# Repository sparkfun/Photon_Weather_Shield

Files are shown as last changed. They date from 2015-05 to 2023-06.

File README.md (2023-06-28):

⛔️ Discontinued
====================
*This product has been retired from our catalog.*

SparkFun_Photon_Weather_Shield
===========================

Photon Weather Shield

[*Photon Weather Shield (DEV-13630 )*](https://www.sparkfun.com/products/13630)

The SparkFun Photon Weather Shield is an easy to use add-on board for the Photon form Particle.io, which  grants you access to barometric pressure, relative humidity, and temperature. There are also connections on this shield to optional sensors such as wind speed, direction, rain gauge and soil readings!

Repository Contents
-------------------

* **/Firmware** - Necessary libraies and example sketches to use the weather shield. 
* **/Hardware** - All Eagle design files (.brd, .sch)
* **/Production** - Test bed files and production panel files

Documentation
--------------
* **[Hookup Guide](https://learn.sparkfun.com/tutorials/photon-weather-shield-hookup-guide)** - Complete hookup guide for the Photon Wetaher Shield.
* **[SparkFun Fritzing repo](https://github.com/sparkfun/Fritzing_Parts)** - Fritzing diagrams for SparkFun products.
* **[SparkFun 3D Model repo](https://github.com/sparkfun/3D_Models)** - 3D models of SparkFun products. 

Product Versions
----------------
* [DEV-13630](https://www.sparkfun.com/products/13630)- Hardware version 1.0

Version History
---------------

License Information
-------------------

This product is _**open source**_! 

Please review the LICENSE.md file for license information. 

If you have any questions or concerns on licensing, please contact techsupport@sparkfun.com.

Distributed as-is; no warranty is given.

- Your friends at SparkFun.

MenloParkInnovation LLC Fork of SparkFun_Photon_Weather_Shield
===========================

The MenloParkInnovation LLC Fork of the SparkFun WeatherShield contains fixes for
the Phant HTTP transfer loop, and a re-written version of the main project
that adds Particle Cloud management, and connections to Smartpux/Openpux
at https://github.com/menloparkinnovation/openpux

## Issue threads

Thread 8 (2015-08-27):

New Photon Weather Shield Library

JoelEB, 2015-08-27:
@danfein Hi, just so you're aware, I combined the HTU21D, Si7021 and MPL3115A2 libraries into one library, found here: https://github.com/sparkfun/SparkFun_Photon_Weather_Shield_Particle_Library. This was mostly to eliminate the need to import two libraries while using the Particle Build IDE. It was also created to support both the HTU21D and Si7021 temp/humidity sensors. We had to switch to the SI7021 on some of our batches due to shortages of the HTU and to meet our deadline with Microsoft. We will be switching the Si chip in a future revision of the shield, so this allows the end user to use both version so the shield seamlessly. If you want to incorporate that new library into your example, fell free. Thanks again.

Closed 2016-03-03.

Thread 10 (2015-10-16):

Variable 'dailyrainin' never resets

georgep56, 2015-10-16:
I'm new to GitHub so I'm sorry if I'm not following protocol ;-)

In the file 'SparkFun_Photon_Weather_Basic_Soil_Meters.ino' I've noticed that the value 'dailyrainin' (rain inches so far today in local time) never gets reset. I've made this small addition to my code towards the bottom of 'loop()':

```
    currentTime = Time.now();

    if ((Time.hour(currentTime) == 0) && (Time.minute(currentTime) == 0) && (Time.second(currentTime) == 0)){
        DailyRainIn = 0;
    }
```

jim-c-sims, 2016-02-13:
I noticed the same thing. I'm guessing that I need to add an I2C real time clock. Is that what you did?

georgep56, 2016-02-13:
Yes, my hardware comprised an arduino and an i2c rtc so had access to the time of day.

wmjenk, 2016-02-13:
Note that the method George used gets current UTC time and would need to be corrected for your time zone if you want to reset at midnight local time. Note also that the UTC time does not adjust for daylight savings time. George’s code works fine with the photon and the weather shield just adjust for your time zone.

Bill

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

santaimpersonator, 2023-06-28:
This product has been retired for some time now and this issue hasn't been addressed for a while. I am closing this issue before archiving the repo.

Closed 2023-06-28.

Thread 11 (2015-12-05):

Wind Direction changes needed if you plan to upload to Weather Underground

wmjenk, 2015-12-05:
Note that "winddir" in the sample code is parsed by the value of the ADC ranges into eight integers 0-7 representing N,NE,E,SE,S,SW,W,NW. The sample code then uses these 0-7 integers to select the correct direction text to output to the serial line. However Weather Underground is expecting "winddir" to be an integer between 0-360 representing a direction in degrees. A simple solution is to replace the integers 0-7 in the get_wind_direction with the direction in degrees, 0, 45, 90,135,180,225,270,315. The same directional integer values can be substituted for the 0-7 values in the serial print routine. Note also that the get_wind_direction routine returns a "-1" if it fails to return one of the defined adc range values. This is a problem for Weather Underground as a -1 is considered an inappropriate value for wind direction and the site will be flagged for reporting inaccurate data. You should avoid uploading any wind directional data values outside the 0-360 range to Weather Underground.

santaimpersonator, 2023-06-28:
This product has been retired for some time now and this issue hasn't been addressed for a while. I am closing this issue before archiving the repo.

Closed 2023-06-28.

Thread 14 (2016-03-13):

Windspeedmph step function

hartmms, 2016-03-13:
I modified the X to post several variables up to Weather Underground. I'm noticing the windspeedmph variable has very few values: 0, 7.2, 14.5, etc.  Is anyone else noticing the same thing?

cwrisley, 2016-03-14:
yes, I noticed the same thing (sort of)
I added
Spark.publish("Wind Speed", String(windspeedmph) + "mph");
delay(2000);
So I could monitor the figures on that I was uploading, and I see alot of this:
{"data":"3.926316mph","ttl":"60","published_at":"2016-03-14T00:29:14.482Z","coreid":"XXXXXXXXX","name":"Wind Speed"}
{"data":"3.905759mph","ttl":"60","published_at":"2016-03-14T00:30:26.544Z","coreid":"XXXXXXXXX","name":"Wind Speed"}
{"data":"7.852632mph","ttl":"60","published_at":"2016-03-14T00:28:01.617Z","coreid":"XXXXXXXXX","name":"Wind Speed"}

Summary: they are "different" numbers, but they seem to close to be true...

hartmms, 2016-03-14:
What frequency are you  calling the "getWeather()"  function. That's the one that actually sets that variable.

Looking at the code closer, the "loop" runs every second and always calls get_wind_speed before "getWeather()":
```
currentSpeed = get_wind_speed()
.
.
.
if (count == X) {
  getWeather()
    windspeedmph = get_wind_speed()
```

So the windspeedmph variable really isn't much different than "currentSpeed". Also note the 2nd call to "get_wind_speed" happens as fast as the code can execute the stuff in between (and other system tasks). I'll bet this elapsed time is so small there are very few windIRQs, causing the step function we see. I'll change my code to post "currentSpeed", which would allow the windIRQ to have a full second of counts to calculate from. Maybe that would result in something better.

cwrisley, 2016-03-14:
Not going to lie, I'm very new to this (aka this is my first ever project of any sort), I'll try to answer... I started with the code posted here on github, but really did alot of commenting it out to get it to post "some" data to wunderground (still working on other fields (windgust etc...http://www.wunderground.com/personal-weather-station/dashboard?ID=KNYESSEX3#history), so I'll try to answer.

I think this answers your question:

 getWeather();
    //Rather than use a delay, keeping track of a counter allows the photon to
    // still take readings and do work in between printing out data.
    count++;
    //alter this number to change the amount of time between each reading
    if(count == 5)
    {
       printInfo();
       count = 0;

    //Send data to Weather Underground
        sendToWU();
    }
  }

I do recall having to mess around and getting errors when trying to save around current speed and wind speed, I might have switched them around at some point....

int WDIR = A0;
int RAIN = D2;
int WSPEED = D3;
int currentTime = 0;

//Global Variables
//-=-=-=-=-=-=-=-=-=-=-=-=-=-=-=-=-=-=-=-=-=-=-=-=-=-=-=-=
long lastSecond; //The millis counter to see when a second rolls by
byte seconds; //When it hits 60, increase the current minute
byte seconds_2m; //Keeps track of the "wind speed/dir avg" over last 2 minutes array of data
byte minutes; //Keeps track of where we are in various arrays of data
byte minutes_10m; //Keeps track of where we are in wind gust/dir over last 10 minutes array of data

int winddir = 0; // [0-360 instantaneous wind direction]
float windspeedmph = 0; // [mph instantaneous wind speed]
float windgustmph = 0; // [mph current wind gust, using software specific time period]
int windgustdir = 0; // [0-360 using software specific time period]
float windspdmph_avg2m = 0; // [mph 2 minute average wind speed mph]
int winddir_avg2m = 0; // [0-360 2 minute average wind direction]
float windgustmph_10m = 0; // [mph past 10 minutes wind gust mph ]
int windgustdir_10m = 0; // [0-360 past 10 minutes wind gust direction]
float rainin = 0; // [rain inches over the past hour)] -- the accumulated rainfall in the past 60 min
long lastWindCheck = 0;
volatile float dailyrainin = 0; // [rain inches so far today in local time]
volatile long lastWindIRQ = 0;
volatile byte windClicks = 0;
volatile unsigned long raintime, rainlast, raininterval, rain;
float humidity = 0;
float tempf = 0;
float tempc = 0;
//double InTempC = 0;//original temperature in C from DS18B20
//float soiltempf = 0;//converted temperature in F from DS18B20
float dewptc = 0;
float dewptF = 0;
float dewptf = 0;
float dewptC = 0;
float tempC = 0;
float pascals = 0;
float altf = 0;
float baroTemp = 0;
//int soilMoisture = 0;
float humTempF = 0;  //humidity sensor temp reading, fahrenheit
float humTempC = 0;  //humidity sensor temp reading, celsius
float baroTempF = 0; //barometer sensor temp reading, fahrenheit
float baroTempC = 0; //barometer sensor temp reading, celsius
float inches = 0;

int count = 0;

void wspeedIRQ()
// Activated by the magnet in the anemometer (2 ticks per rotation), attached to input D3
{
  if (millis() - lastWindIRQ > 10) // Ignore switch-bounce glitches less than 10ms (142MPH max reading) after the reed switch closes
  {
    lastWindIRQ = millis(); //Grab the current time
    windClicks++; //There is 1.492MPH for each click per second.
  }
}

________________

hartmms, 2016-03-14:
Thanks for the input, but I'm not sure that will fix the issue. Based on my testing, I'm pretty sure it's the 2nd call to get_wind_speed() so close to the original call that leaves nearly zero time for "windIRQ" to trigger and generate any meaningful samples.

I re-worked the loop() body to only get the wind speed every 5 seconds. This means I removed the "get_wind_speed" from getWeather() also. Some debug publish events later, and I can see much more realistic wind measurements. No more step function!

Unfortunately, I've added so much of my own custom code that submitting a pull request is no longer appropriate.

However, here is a sample of the new wind measurement part of my loop():

```
    long now = Time.now();
    hour = Time.hour(now);
    minute = Time.minute(now);
    second = Time.second(now);
    // If a new day, reset vars that keep the daily totals
    if (hour == 0 && minute == 0 && second == 0) {
      dailyrainin = 0;
      windgustmph = 0;
    }
    //Calc the wind speed every 5 seconds
    if ((second+1) % 5 == 0) {
      currentSpeed = get_wind_speed();
      int currentDirection = get_wind_direction();
      windspdavg[seconds_2m] = (int)currentSpeed;
      winddiravg[seconds_2m] = currentDirection;
      //Check to see if this is a gust for the minute
      if (currentSpeed > windgust_10m[minutes_10m]) {
        windgust_10m[minutes_10m] = currentSpeed;
        windgustdirection_10m[minutes_10m] = currentDirection;
      }
      //Check to see if this is a gust for the day
      if (currentSpeed > windgustmph) {
        windgustmph = currentSpeed;
        windgustdir = currentDirection;
      }
    }
```

I'm now using the currentSpeed variable to post the WU value of "windspeedmph". Be sure to remove the winddir, windspeedmph, windgustmph, windgustdir from the getWeather() function.

gringofr, 2020-07-11:
hello hartmms,
It has been several weeks since I have broken my head with the code for my weather station, will you be kind enough to share your code which looks functional.

thank you in advance

santaimpersonator, 2023-06-28:
This product has been retired for some time now and this issue hasn't been addressed for a while. I am closing this issue before archiving the repo.

Closed 2023-06-28.

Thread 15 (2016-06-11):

rain sensor triggers incorrectly

hartmms, 2016-06-11:
Anyone else seeing the rain IRQ trigger incorrectly? I see the code has some basic debounce code to it, so I doubt that's the issue.  Is the sensor that sensitive to vibration/high wind gusts?

santaimpersonator, 2023-06-28:
This product has been retired for some time now and this issue hasn't been addressed for a while. I am closing this issue before archiving the repo.

Closed 2023-06-28.

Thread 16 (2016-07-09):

Does not work with negative temperatures on 32-bit processors

jkardach, 2016-07-09:
Hi,
On an ARM processor the temperature is not converted from the two byte registers into a float correctly and the sign is not extended resulting in a large positive number when the temperature goes below zero.
The issue occurs in the rawToCelisius method, where it a sixteen bit integer into a four byte float.  I'm guessing the casting of the 16-bit integer raw to a float must first cast to a 4 byte integer without sign-extending the upper two bytes, which then results in a larger positive integer (versus a small negative integer) before it is converted to a float.

// convert from raw to Celsius
float DallasTemperature::rawToCelsius(int16_t raw)
{
    if (raw <= DEVICE_DISCONNECTED_RAW)
        return DEVICE_DISCONNECTED_C;
    // C = RAW/128
    return (float)raw \* 0.0078125;
}

I was able to get negative results by doing the following:

```
    int temp4 = RAW;      // on ARM this is a 4byte integer, upper two bytes zero
if (RAW&0x8000) {    // check high bit of RAW to see if negative
    temp4 = temp4 | 0xFFFF0000;    // sign extend to upper 2 bytes for negative
} else {
    temp4 = temp4 & 0x0000FFFF;  // sign extend to upper 2 bytes for positive
}
    return (float) temp4* 0.0078125;        // convert to floating
```

I'm not a a great programmer, but I figure someone who is can update the library so that it will work properly on 32-bit, 16-bit and 8-bit processors.

thanks,
Jim Kardach

santaimpersonator, 2023-06-28:
This product has been retired for some time now and this issue hasn't been addressed for a while. I am closing this issue before archiving the repo.

Closed 2023-06-28.

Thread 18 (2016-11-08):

v11 checklist issues

ericorosel, 2016-11-08:
(1) The "SDA" trace is exposed by the tSTOP of R5. The trace could be moved down to eliminate excessive tSTOP related trace exposure.

(2) The "3.3V" trace is exposed by pin 4 of the MPL. The trace could be moved down to eliminate excessive tSTOP related trace exposure.

(3) It looks like the Si7021 package is missing tSTOP for the center pad, but does have a tCREAM polygon. As it stands, it looks like we will be pasting onto mask where the center pad will should be. This is also present in the Weather Shield which uses the same package.

JoelEB, 2016-11-08:
Fixed tSTOP of 1) and 2).

Added tSTOP to Si7021 footprint in parts library, Updated part on both this board as well as the Arduino Weather Shield. Rev.

Closed 2016-11-08.

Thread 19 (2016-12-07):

Double check v11

edspark, 2016-12-07:
1) Are any jumpers labeled clearly by their function and possible settings? [YES]
comment: SJ3 Jumper has a spelling error "dissconnect" instead of "disconnect".

2) Have you verified that the BOM in Sparkle is accurate (also checking for PROD_ID, NAME, VALUE, PREFIX)? [YES]
comment: Missing CONN-09696 on the BOM and CONN-13002 is on the Sparkle Page but not on the BOM

3) Does it pass SparkFun DRC? [NO]
comment: No but we cruised through all 250+ errors and it's cool Joel.

4) Do all footprints have 0.008 inch silk footprint? [NO]
comment: Nope but its cool.

5) Is the polarity label outside of the package for visibility after part population? [NO]
comment: NO but it's cool.

6) The values for Diodes D8, D10, and D6 overlap nearby nets!

JoelEB, 2016-12-09:
Pete - What do you mean by "CONN-13002 is on the Sparkle Page but not on the BOM" I see it in the BOM in Sparkle. They've been building them correctly thus far, so I'm assuming it's correct.

Fixed issue 1 and 6. Discussed issues 3, 4 and 5 with Pete in person.

Closing.

Closed 2016-12-09.

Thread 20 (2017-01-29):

sensors is wrong, does not compile for 6 ino files

hanscees, 2017-01-29:
hi

sensors.begin();
does not compile.
all sensorS should be sensor. S is wrong. Error introduced with soil temperature code

this error is in all ino files made 11 months ago. Took me a while to find it.

santaimpersonator, 2023-06-28:
This product has been retired for some time now and this issue hasn't been addressed for a while. I am closing this issue before archiving the repo.

Closed 2023-06-28.

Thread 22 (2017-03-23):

Arduino & photon weather shield

WillemSpectrum, 2017-03-23:
Are you somehow able to hook up the sparkfun photon weather shield to an arduino genuino uno?

Thanks in advance

JoelEB, 2017-03-23:
Hi, If you're looking for something that will fit on an Uno, check out our[ Arduino Weather Shield](https://www.sparkfun.com/products/13956). It is very similar to the Photon Weather Shield.

WillemSpectrum, 2017-03-24:
@JoelEB alright thank you, i think me and my classmate have made the wrong purchase then.

Closed 2017-03-23.

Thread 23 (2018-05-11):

No need to wait after Wire.requestFrom().

Koepel, 2018-05-11:
See https://github.com/sparkfun/SparkFun_Photon_Weather_Shield_Particle_Library/issues/6

santaimpersonator, 2023-06-28:
This product has been retired for some time now and this issue hasn't been addressed for a while. I am closing this issue before archiving the repo.

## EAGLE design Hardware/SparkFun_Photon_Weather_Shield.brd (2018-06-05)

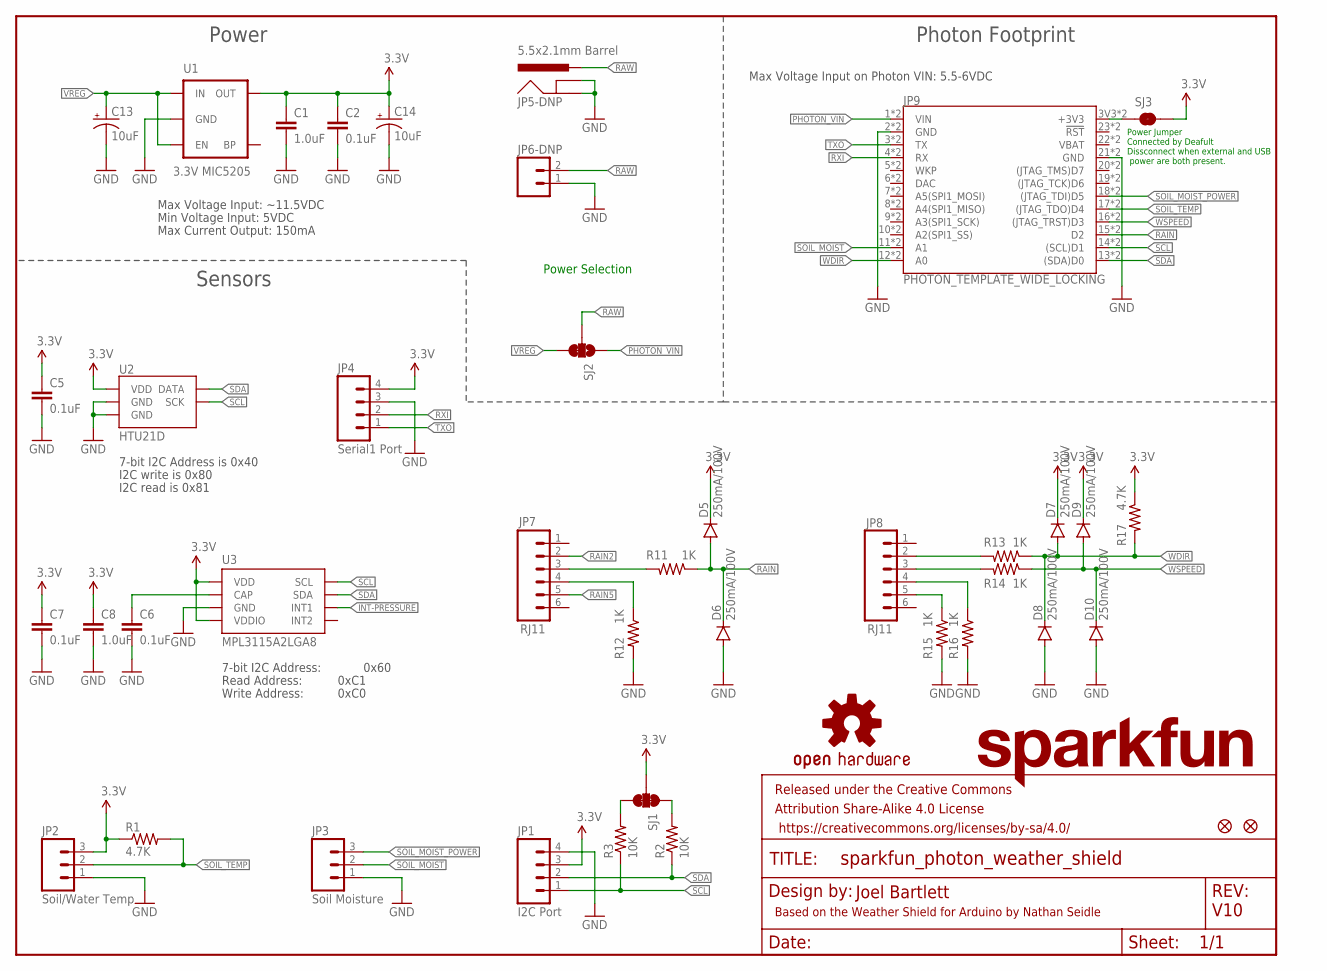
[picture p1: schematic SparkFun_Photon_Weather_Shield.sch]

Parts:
C1, C8: 1.0uF; 0603-CAP
C2, C5, C6, C7: 0.1uF; 0603-CAP
C13, C14: 10uF; EIA3216
D5, D6, D7, D8, D9, D10: 250mA/100V; SOD-323
FID1, FID2: FIDUCIAL1X2; FIDUCIAL-1X2
FRAME1: FRAME-LETTER; CREATIVE_COMMONS
JP1: I2C Port; 1X04
JP2: Soil/Water Temp; 1X03
JP3: Soil Moisture; 1X03
JP4: Serial1 Port; 1X04
JP5-DNP: 5.5x2.1mm Barrel; POWER_JACK_SMD
JP6-DNP: M023.5MM; SCREWTERMINAL-3.5MM-2
JP7, JP8: RJ11; RJ11-6
JP9: PHOTON_TEMPLATE_WIDE_LOCKING; SPARK_PHOTON_TEMPLATE_WIDE_LOCKING
LOGO1: OSHW-LOGOM; OSHW-LOGO-M
LOGO2: SFE_LOGO_NAME.1_INCH; SFE_LOGO_NAME_.1
R1, R17: 4.7K; 0603-RES
R2, R3: 10K; 0603-RES
R11, R12, R13, R14, R15, R16: 1K; 0603-RES
SJ1: JUMPER-PAD-3-NC_BY_TRACE; PAD-JUMPER-3-3OF3_NC_BY_TRACE_YES_SILK_FULL_BOX
SJ2: JUMPER-PAD-3-2OF3_NC_BY_TRACE_SMALL; PAD-JUMPER-3-2OF3_NC_BY_TRACE_YES_SILK_FULL_BOX
SJ3: JUMPER-PAD-2-NC_BY_TRACE; PAD-JUMPER-2-NC_BY_TRACE_YES_SILK
U1: 3.3V MIC5205; SOT23-5
U2: HTU21D
U3: MPL3115A2LGA8; LGA8

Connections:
3.3V: C1.1, C2.1, C5.1, C7.1, C8.1, C14.A (+), D5.C, D7.C, D9.C, JP1.3, JP2.3, JP4.4, R1.1, R17.1, SJ1.2, SJ3.2, U1.5 (OUT), U2.VDD, U3.1 (VDD), U3.4 (VDDIO)
GND: C1.2, C2.2, C5.2, C6.2, C7.2, C8.2, C13.C (-), C14.C (-), D6.A, D8.A, D10.A, JP1.4, JP2.1, JP3.1, JP4.3, JP5-DNP.GND (GNDBREAK), JP5-DNP.P$4 (GND), JP6-DNP.1, JP9.2 (GND), JP9.21 (GND), JP9.GND@0 (GND), JP9.GND@2 (GND), R12.2, R15.2, R16.2, U1.2 (GND), U2.7 (GND), U2.GND, U3.3 (GND)
INT-PRESSURE: U3.6 (INT1)
unnamed: JP8.3, R14.2
unnamed: JP8.2, R13.2
unnamed: R3.2, SJ1.3
unnamed: JP7.3, R11.2
unnamed: C6.1, U3.2 (CAP)
unnamed: R2.2, SJ1.1
unnamed: JP9.3V3 (+3V3), JP9.24 (+3V3), SJ3.1
unnamed: JP7.4, R12.1
unnamed: JP8.5, R15.1
unnamed: JP8.4, R16.1
PHOTON_VIN: JP9.1 (VIN), JP9.VIN, SJ2.1
RAIN: D5.A, D6.C, JP9.15 (D2), JP9.D2, R11.1
RAIN2: JP7.2
RAIN5: JP7.5
RAW: JP5-DNP.VIN0 (PWR), JP6-DNP.2, SJ2.2
RXI: JP4.2, JP9.4 (RX), JP9.RX
SCL: JP1.1, JP9.14 ((SCL)D1), JP9.D1 ((SCL)D1), R3.1, U2.SCK, U3.8 (SCL)
SDA: JP1.2, JP9.13 ((SDA)D0), JP9.D0 ((SDA)D0), R2.1, U2.DATA, U3.7 (SDA)
SOIL_MOIST: JP3.2, JP9.11 (A1), JP9.A1
SOIL_MOIST_POWER: JP3.3, JP9.18 ((JTAG_TDI)D5), JP9.D5 ((JTAG_TDI)D5)
SOIL_TEMP: JP2.2, JP9.17 ((JTAG_TDO)D4), JP9.D4 ((JTAG_TDO)D4), R1.2
TXO: JP4.1, JP9.3 (TX), JP9.TX
VREG: C13.A (+), SJ2.3, U1.1 (IN), U1.3 (EN)
WDIR: D7.A, D8.C, JP9.12 (A0), JP9.A0, R13.1, R17.2
WSPEED: D9.A, D10.C, JP9.16 ((JTAG_TRST)D3), JP9.D3 ((JTAG_TRST)D3), R14.1

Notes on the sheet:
Max Voltage Input: ~11.5VDC
Max Current Output: 150mA
Read Address:
Write Address:
7-bit I2C Address:
0x60
0xC1
0xC0
7-bit I2C Address is 0x40
I2C write is 0x80
I2C read is 0x81
Sensors
Power
Photon Footprint
Power Selection
Based on the Weather Shield for Arduino by Nathan Seidle
Min Voltage Input: 5VDC
Power Jumper Connected by Deafult Dissconnect when external and USB power are both present.
Joel Bartlett
V10
Max Voltage Input on Photon VIN: 5.5-6VDC

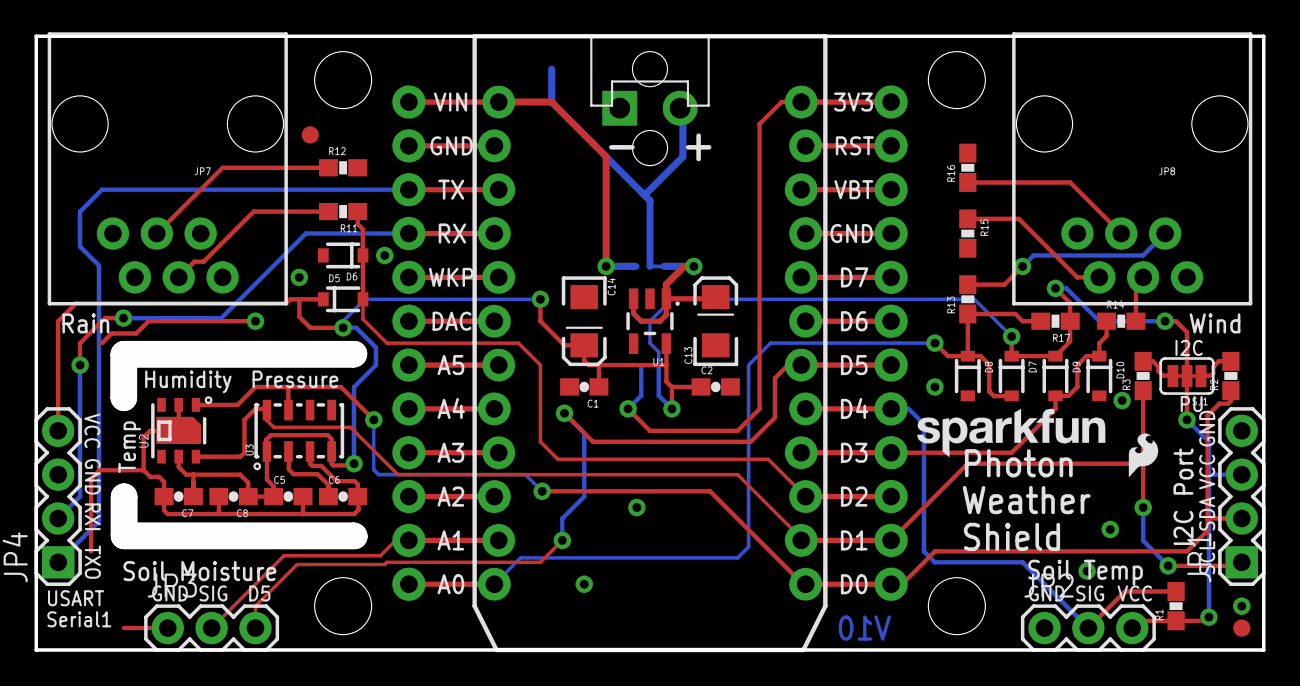
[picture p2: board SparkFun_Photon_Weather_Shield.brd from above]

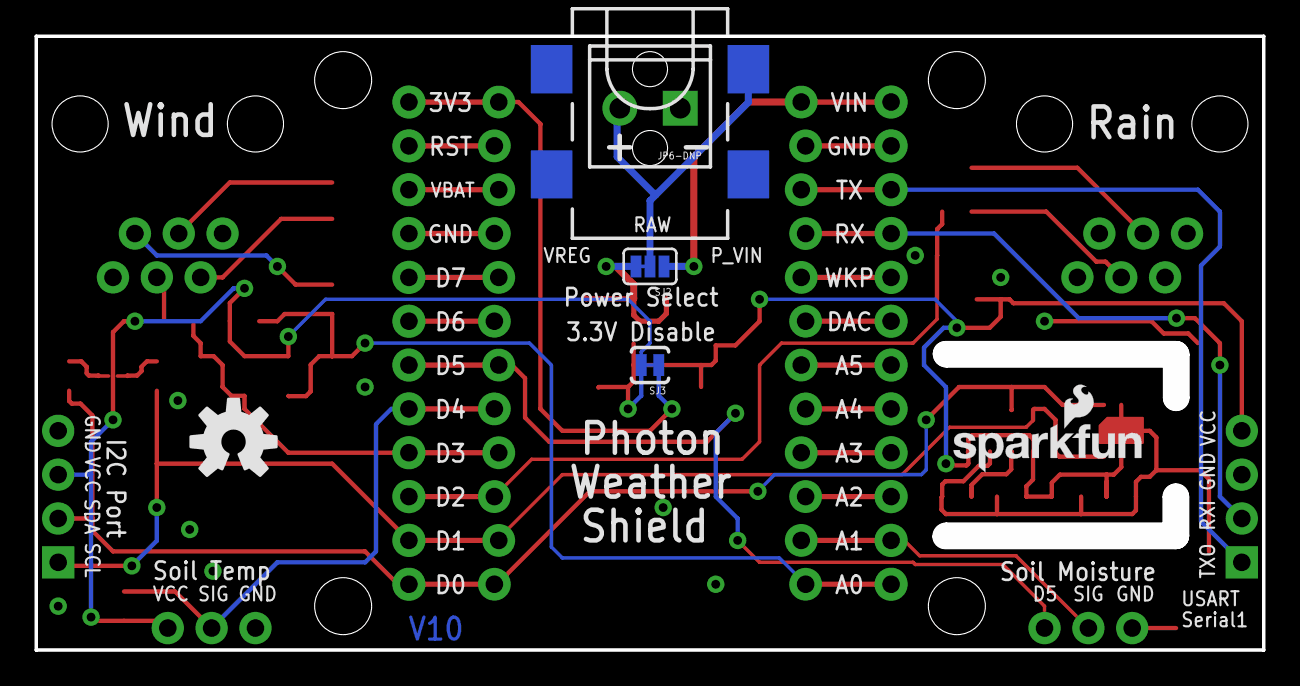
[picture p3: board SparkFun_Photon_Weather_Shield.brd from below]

Board: 2 copper layers, 71.1 x 35.6 mm, 46 parts (6 on the bottom side), 25 nets.

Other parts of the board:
U$1: SFE_LOGO_NAME_FLAME_.1
U$3: SFE_LOGO_FLAME_.1

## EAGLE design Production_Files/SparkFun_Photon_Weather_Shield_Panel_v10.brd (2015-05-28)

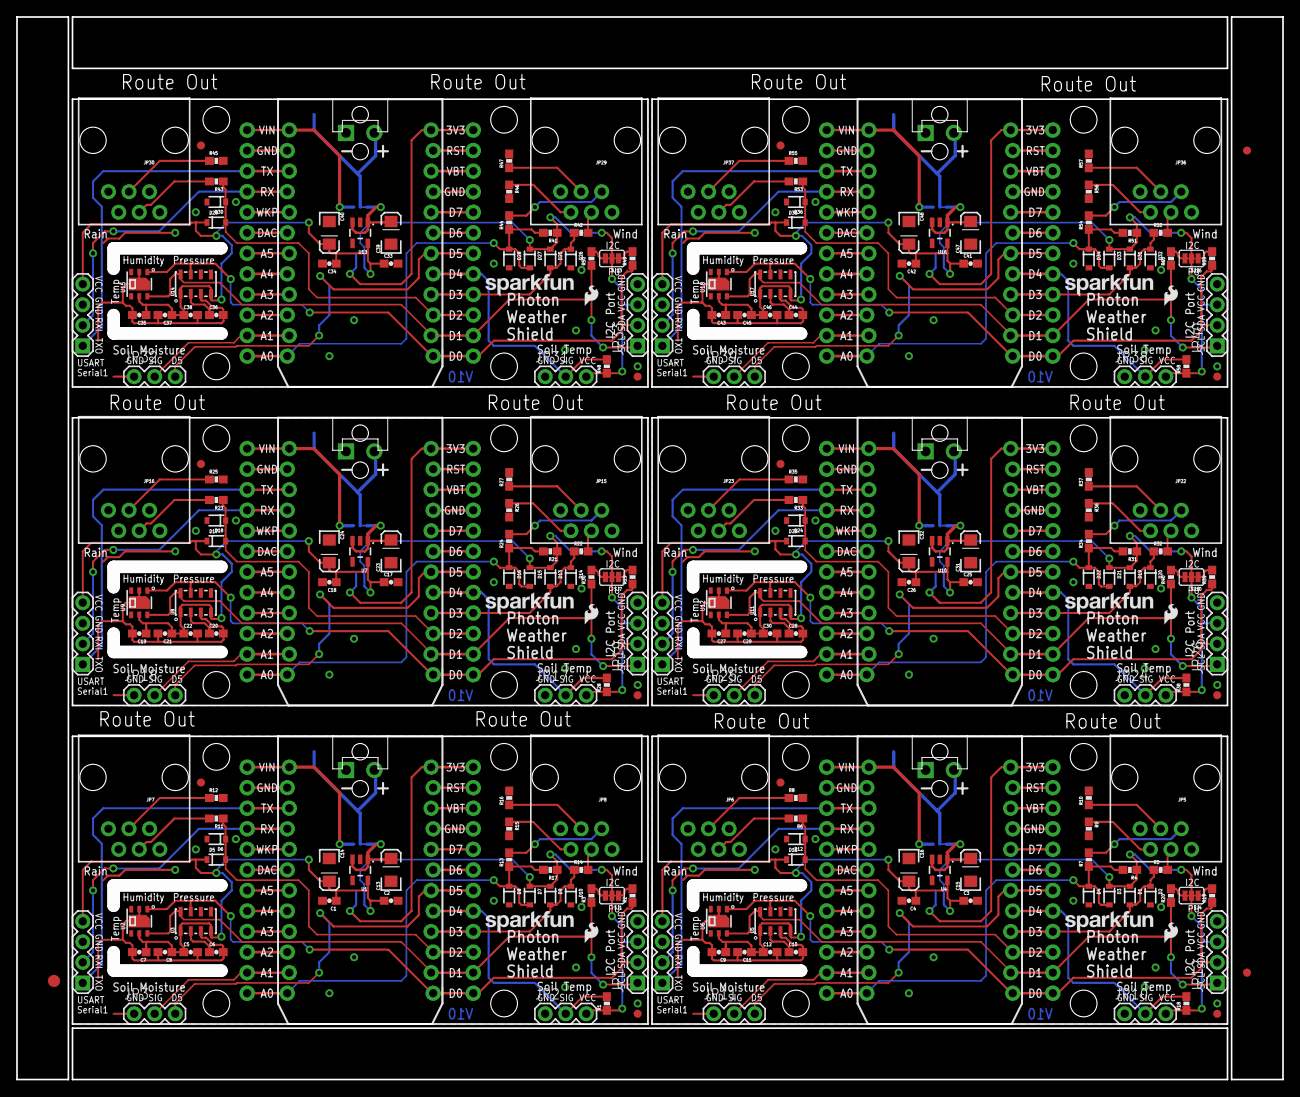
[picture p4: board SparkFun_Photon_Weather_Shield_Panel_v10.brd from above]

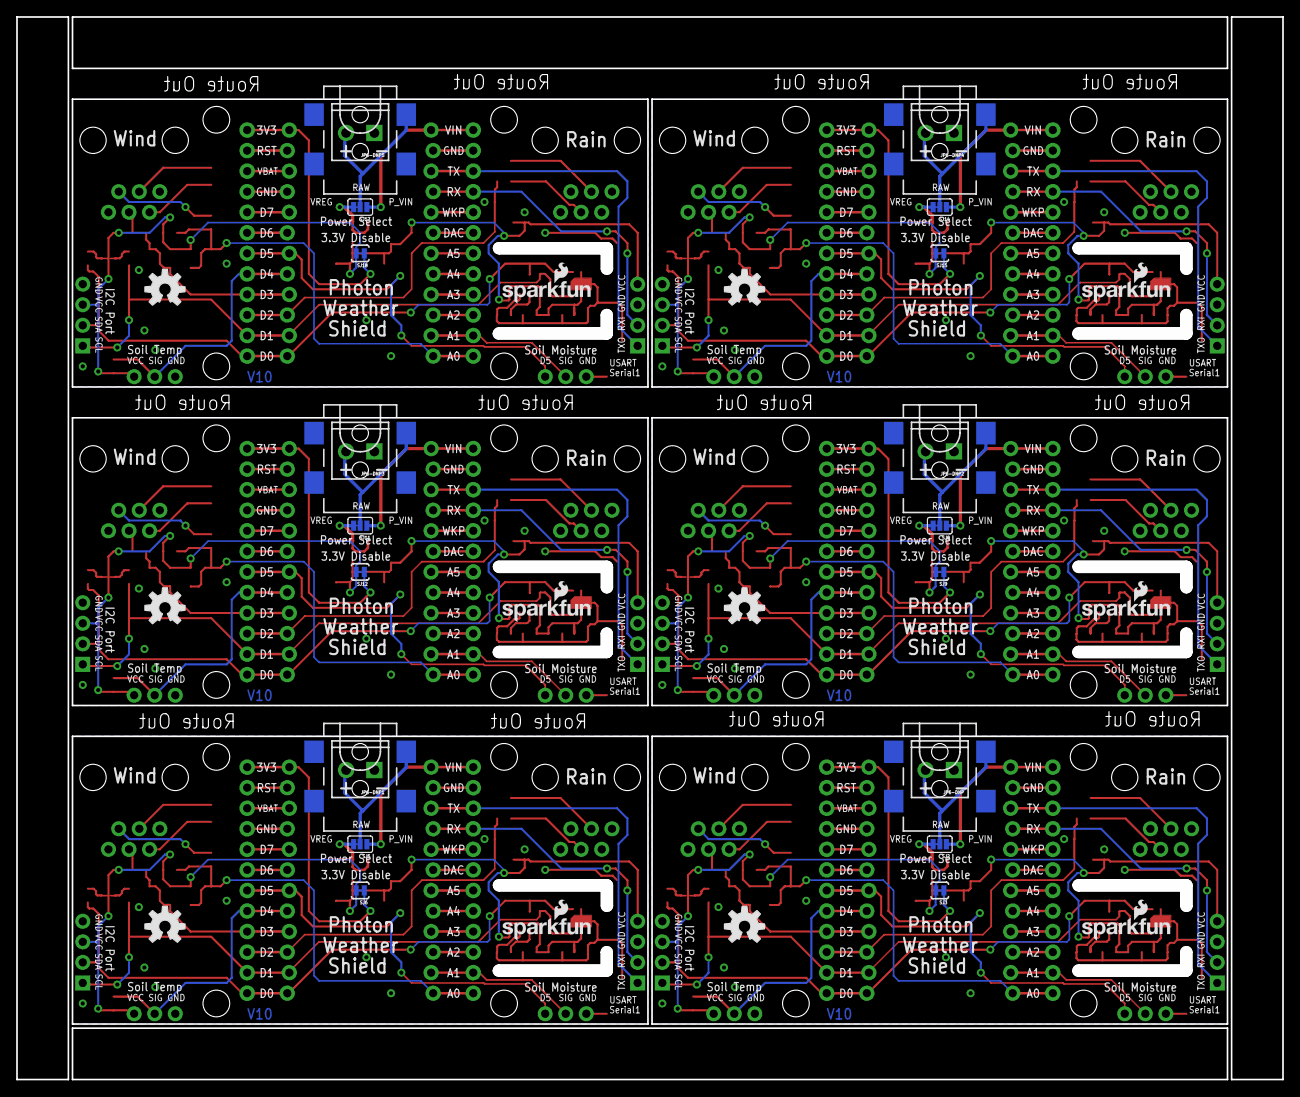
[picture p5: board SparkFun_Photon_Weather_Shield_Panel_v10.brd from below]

Board: 2 copper layers, 156.5 x 131.3 mm, 273 parts (36 on the bottom side), 150 nets.

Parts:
C1, C4, C8, C11, C18, C21, C26, C29, C34, C37, C42, C45: 1.0uF; 0603-CAP
C2, C3, C5, C6, C7, C9, C10, C12, C17, C19, C20, C22, C25, C27, C28, C30, C33, C35, C36, C38, C41, C43, C44, C46: 0.1uF; 0603-CAP
C13, C14, C15, C16, C23, C24, C31, C32, C39, C40, C47, C48: 10uF; EIA3216
D1, D2, D3, D4, D5, D6, D7, D8, D9, D10, D11, D12, D13, D14, D15, D16, D17, D18, D19, D20, D21, D22, D23, D24, D25, D26, D27, D28, D29, D30, D31, D32, D33, D34, D35, D36: 250mA/100V; SOD-323
E$1: FIDUCIAL-1.5X3
E$3, E$4: FIDUCIAL-1X2
FID1, FID2, FID3, FID4, FID5, FID6, FID7, FID8, FID9, FID10, FID11, FID12: FIDUCIAL1X2; FIDUCIAL-1X2
JP1, JP12, JP19, JP26, JP33, JP40: I2C Port; 1X04
JP2, JP10, JP17, JP24, JP31, JP38: Soil/Water Temp; 1X03
JP3, JP11, JP18, JP25, JP32, JP39: Soil Moisture; 1X03
JP4, JP13, JP20, JP27, JP34, JP41: Serial1 Port; 1X04
JP5, JP6, JP7, JP8, JP15, JP16, JP22, JP23, JP29, JP30, JP36, JP37: RJ11; RJ11-6
JP5-DNP, JP5-DNP1, JP5-DNP2, JP5-DNP3, JP5-DNP4, JP5-DNP5: 5.5x2.1mm Barrel; POWER_JACK_SMD
JP6-DNP, JP6-DNP1, JP6-DNP2, JP6-DNP3, JP6-DNP4, JP6-DNP5: SCREWTERMINAL-3.5MM-2
JP9, JP14, JP21, JP28, JP35, JP42: PHOTON_TEMPLATE_WIDE_LOCKING; SPARK_PHOTON_TEMPLATE_WIDE_LOCKING
LOGO1, LOGO3, LOGO5, LOGO7, LOGO9, LOGO11: OSHW-LOGOM; OSHW-LOGO-M
LOGO2, LOGO4, LOGO6, LOGO8, LOGO10, LOGO12: SFE_LOGO_NAME.1_INCH; SFE_LOGO_NAME_.1
R1, R4, R17, R18, R21, R28, R31, R38, R41, R48, R51, R58: 4.7K; 0603-RES
R2, R3, R19, R20, R29, R30, R39, R40, R49, R50, R59, R60: 10K; 0603-RES
R5, R6, R7, R8, R9, R10, R11, R12, R13, R14, R15, R16, R22, R23, R24, R25, R26, R27, R32, R33, R34, R35, R36, R37, R42, R43, R44, R45, R46, R47, R52, R53, R54, R55, R56, R57: 1K; 0603-RES
SJ1, SJ4, SJ7, SJ10, SJ13, SJ16: PAD-JUMPER-3-3OF3_NC_BY_TRACE_YES_SILK_FULL_BOX
SJ2, SJ5, SJ8, SJ11, SJ14, SJ17: PAD-JUMPER-3-2OF3_NC_BY_TRACE_YES_SILK_FULL_BOX
SJ3, SJ6, SJ9, SJ12, SJ15, SJ18: PAD-JUMPER-2-NC_BY_TRACE_YES_SILK
U1, U4, U7, U10, U13, U16: 3.3V MIC5219; SOT23-5
U2, U6, U9, U12, U15, U18: HTU21D
U3, U5, U8, U11, U14, U17: MPL3115A2LGA8; LGA8
U$1, U$2, U$5, U$7, U$9, U$11: SFE_LOGO_NAME_FLAME_.1
U$3, U$4, U$6, U$8, U$10, U$12: SFE_LOGO_FLAME_.1

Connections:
3.3V: C1.1, C2.1, C5.1, C7.1, C8.1, C14.A, D5.C, D7.C, D9.C, JP1.3, JP2.3, JP4.4, R1.1, R17.1, SJ1.2, SJ3.2, U1.5, U2.VDD, U3.1, U3.4
3.3V1: C3.1, C4.1, C9.1, C11.1, C12.1, C16.A, D1.C, D3.C, D11.C, JP10.3, JP12.3, JP13.4, R4.1, R18.1, SJ4.2, SJ6.2, U4.5, U5.1, U5.4, U6.VDD
3.3V2: C17.1, C18.1, C19.1, C21.1, C22.1, C24.A, D13.C, D15.C, D17.C, JP17.3, JP19.3, JP20.4, R21.1, R28.1, SJ7.2, SJ9.2, U7.5, U8.1, U8.4, U9.VDD
3.3V3: C25.1, C26.1, C27.1, C29.1, C30.1, C32.A, D19.C, D21.C, D23.C, JP24.3, JP26.3, JP27.4, R31.1, R38.1, SJ10.2, SJ12.2, U10.5, U11.1, U11.4, U12.VDD
3.3V4: C33.1, C34.1, C35.1, C37.1, C38.1, C40.A, D25.C, D27.C, D29.C, JP31.3, JP33.3, JP34.4, R41.1, R48.1, SJ13.2, SJ15.2, U13.5, U14.1, U14.4, U15.VDD
3.3V5: C41.1, C42.1, C43.1, C45.1, C46.1, C48.A, D31.C, D33.C, D35.C, JP38.3, JP40.3, JP41.4, R51.1, R58.1, SJ16.2, SJ18.2, U16.5, U17.1, U17.4, U18.VDD
GND: C1.2, C2.2, C5.2, C6.2, C7.2, C8.2, C13.C, C14.C, D6.A, D8.A, D10.A, JP1.4, JP2.1, JP3.1, JP4.3, JP5-DNP.GND, JP5-DNP.P$4, JP6-DNP.1, JP9.2, JP9.21, JP9.GND@0, JP9.GND@2, R12.2, R15.2, R16.2, U1.2, U2.7, U2.GND, U3.3
GND1: C3.2, C4.2, C9.2, C10.2, C11.2, C12.2, C15.C, C16.C, D2.A, D4.A, D12.A, JP5-DNP1.GND, JP5-DNP1.P$4, JP6-DNP1.1, JP10.1, JP11.1, JP12.4, JP13.3, JP14.2, JP14.21, JP14.GND@0, JP14.GND@2, R8.2, R9.2, R10.2, U4.2, U5.3, U6.7, U6.GND
GND2: C17.2, C18.2, C19.2, C20.2, C21.2, C22.2, C23.C, C24.C, D14.A, D16.A, D18.A, JP5-DNP2.GND, JP5-DNP2.P$4, JP6-DNP2.1, JP17.1, JP18.1, JP19.4, JP20.3, JP21.2, JP21.21, JP21.GND@0, JP21.GND@2, R25.2, R26.2, R27.2, U7.2, U8.3, U9.7, U9.GND
GND3: C25.2, C26.2, C27.2, C28.2, C29.2, C30.2, C31.C, C32.C, D20.A, D22.A, D24.A, JP5-DNP3.GND, JP5-DNP3.P$4, JP6-DNP3.1, JP24.1, JP25.1, JP26.4, JP27.3, JP28.2, JP28.21, JP28.GND@0, JP28.GND@2, R35.2, R36.2, R37.2, U10.2, U11.3, U12.7, U12.GND
GND4: C33.2, C34.2, C35.2, C36.2, C37.2, C38.2, C39.C, C40.C, D26.A, D28.A, D30.A, JP5-DNP4.GND, JP5-DNP4.P$4, JP6-DNP4.1, JP31.1, JP32.1, JP33.4, JP34.3, JP35.2, JP35.21, JP35.GND@0, JP35.GND@2, R45.2, R46.2, R47.2, U13.2, U14.3, U15.7, U15.GND
GND5: C41.2, C42.2, C43.2, C44.2, C45.2, C46.2, C47.C, C48.C, D32.A, D34.A, D36.A, JP5-DNP5.GND, JP5-DNP5.P$4, JP6-DNP5.1, JP38.1, JP39.1, JP40.4, JP41.3, JP42.2, JP42.21, JP42.GND@0, JP42.GND@2, R55.2, R56.2, R57.2, U16.2, U17.3, U18.7, U18.GND
unnamed: JP8.3, R14.2
unnamed: JP8.2, R13.2
unnamed: R3.2, SJ1.3
unnamed: JP7.3, R11.2
unnamed: C6.1, U3.2
unnamed: R2.2, SJ1.1
unnamed: JP9.3V3, JP9.24, SJ3.1
unnamed: C10.1, U5.2
unnamed: JP5.2, R7.2
unnamed: JP5.3, R5.2
unnamed: JP7.4, R12.1
unnamed: JP8.5, R15.1
unnamed: JP8.4, R16.1
unnamed: JP6.3, R6.2
unnamed: JP6.4, R8.1
unnamed: JP5.5, R9.1
unnamed: JP5.4, R10.1
unnamed: R20.2, SJ4.3
unnamed: R19.2, SJ4.1
unnamed: JP14.3V3, JP14.24, SJ6.1
unnamed: C20.1, U8.2
unnamed: JP15.2, R24.2
unnamed: JP15.3, R22.2
unnamed: JP16.3, R23.2
unnamed: JP16.4, R25.1
unnamed: JP15.5, R26.1
unnamed: JP15.4, R27.1
unnamed: R30.2, SJ7.3
unnamed: R29.2, SJ7.1
unnamed: JP21.3V3, JP21.24, SJ9.1
unnamed: C28.1, U11.2
unnamed: JP22.2, R34.2
unnamed: JP22.3, R32.2
unnamed: JP23.3, R33.2
unnamed: JP23.4, R35.1
unnamed: JP22.5, R36.1
unnamed: JP22.4, R37.1
unnamed: R40.2, SJ10.3
unnamed: R39.2, SJ10.1
unnamed: JP28.3V3, JP28.24, SJ12.1
unnamed: C36.1, U14.2
unnamed: JP29.2, R44.2
unnamed: JP29.3, R42.2
unnamed: JP30.3, R43.2
unnamed: JP30.4, R45.1
unnamed: JP29.5, R46.1
unnamed: JP29.4, R47.1
unnamed: R50.2, SJ13.3
unnamed: R49.2, SJ13.1
unnamed: JP35.3V3, JP35.24, SJ15.1
unnamed: C44.1, U17.2
unnamed: JP36.2, R54.2
unnamed: JP36.3, R52.2
unnamed: JP37.3, R53.2
unnamed: JP37.4, R55.1
unnamed: JP36.5, R56.1
unnamed: JP36.4, R57.1
unnamed: R60.2, SJ16.3
unnamed: R59.2, SJ16.1
unnamed: JP42.3V3, JP42.24, SJ18.1
PHOTON_VIN: JP9.1, JP9.VIN, SJ2.1
PHOTON_VIN1: JP14.1, JP14.VIN, SJ5.1
PHOTON_VIN2: JP21.1, JP21.VIN, SJ8.1
PHOTON_VIN3: JP28.1, JP28.VIN, SJ11.1
PHOTON_VIN4: JP35.1, JP35.VIN, SJ14.1
PHOTON_VIN5: JP42.1, JP42.VIN, SJ17.1
RAIN: D5.A, D6.C, JP9.15, JP9.D2, R11.1
RAIN1: D11.A, D12.C, JP14.15, JP14.D2, R6.1
RAIN6: D17.A, D18.C, JP21.15, JP21.D2, R23.1
RAIN9: D23.A, D24.C, JP28.15, JP28.D2, R33.1
RAIN12: D29.A, D30.C, JP35.15, JP35.D2, R43.1
RAIN15: D35.A, D36.C, JP42.15, JP42.D2, R53.1
RAW: JP5-DNP.VIN0, JP6-DNP.2, SJ2.2
RAW1: JP5-DNP1.VIN0, JP6-DNP1.2, SJ5.2
RAW2: JP5-DNP2.VIN0, JP6-DNP2.2, SJ8.2
RAW3: JP5-DNP3.VIN0, JP6-DNP3.2, SJ11.2
RAW4: JP5-DNP4.VIN0, JP6-DNP4.2, SJ14.2
RAW5: JP5-DNP5.VIN0, JP6-DNP5.2, SJ17.2
RXI: JP4.2, JP9.4, JP9.RX
RXI1: JP13.2, JP14.4, JP14.RX
RXI2: JP20.2, JP21.4, JP21.RX
RXI3: JP27.2, JP28.4, JP28.RX
RXI4: JP34.2, JP35.4, JP35.RX
RXI5: JP41.2, JP42.4, JP42.RX
SCL: JP1.1, JP9.14, JP9.D1, R3.1, U2.SCK, U3.8
SCL1: JP12.1, JP14.14, JP14.D1, R20.1, U5.8, U6.SCK
SCL2: JP19.1, JP21.14, JP21.D1, R30.1, U8.8, U9.SCK
SCL3: JP26.1, JP28.14, JP28.D1, R40.1, U11.8, U12.SCK
SCL4: JP33.1, JP35.14, JP35.D1, R50.1, U14.8, U15.SCK
SCL5: JP40.1, JP42.14, JP42.D1, R60.1, U17.8, U18.SCK
SDA: JP1.2, JP9.13, JP9.D0, R2.1, U2.DATA, U3.7
SDA1: JP12.2, JP14.13, JP14.D0, R19.1, U5.7, U6.DATA
SDA2: JP19.2, JP21.13, JP21.D0, R29.1, U8.7, U9.DATA
SDA3: JP26.2, JP28.13, JP28.D0, R39.1, U11.7, U12.DATA
SDA4: JP33.2, JP35.13, JP35.D0, R49.1, U14.7, U15.DATA
SDA5: JP40.2, JP42.13, JP42.D0, R59.1, U17.7, U18.DATA
SOIL_MOIST: JP3.2, JP9.11, JP9.A1
SOIL_MOIST3: JP11.2, JP14.11, JP14.A1
SOIL_MOIST4: JP18.2, JP21.11, JP21.A1
SOIL_MOIST5: JP25.2, JP28.11, JP28.A1
SOIL_MOIST6: JP32.2, JP35.11, JP35.A1
SOIL_MOIST7: JP39.2, JP42.11, JP42.A1
SOIL_MOIST_POWER: JP3.3, JP9.18, JP9.D5
SOIL_MOIST_POWER1: JP11.3, JP14.18, JP14.D5
SOIL_MOIST_POWER2: JP18.3, JP21.18, JP21.D5
SOIL_MOIST_POWER3: JP25.3, JP28.18, JP28.D5
SOIL_MOIST_POWER4: JP32.3, JP35.18, JP35.D5
SOIL_MOIST_POWER5: JP39.3, JP42.18, JP42.D5
SOIL_TEMP: JP2.2, JP9.17, JP9.D4, R1.2
SOIL_TEMP2: JP10.2, JP14.17, JP14.D4, R18.2
SOIL_TEMP3: JP17.2, JP21.17, JP21.D4, R28.2
SOIL_TEMP4: JP24.2, JP28.17, JP28.D4, R38.2
SOIL_TEMP5: JP31.2, JP35.17, JP35.D4, R48.2
SOIL_TEMP6: JP38.2, JP42.17, JP42.D4, R58.2
TXO: JP4.1, JP9.3, JP9.TX
TXO1: JP13.1, JP14.3, JP14.TX
TXO2: JP20.1, JP21.3, JP21.TX
TXO3: JP27.1, JP28.3, JP28.TX
TXO4: JP34.1, JP35.3, JP35.TX
TXO5: JP41.1, JP42.3, JP42.TX
VREG: C13.A, SJ2.3, U1.1, U1.3
VREG1: C15.A, SJ5.3, U4.1, U4.3
VREG2: C23.A, SJ8.3, U7.1, U7.3
VREG3: C31.A, SJ11.3, U10.1, U10.3
VREG4: C39.A, SJ14.3, U13.1, U13.3
VREG5: C47.A, SJ17.3, U16.1, U16.3
WDIR: D7.A, D8.C, JP9.12, JP9.A0, R13.1, R17.2
WDIR1: D3.A, D4.C, JP14.12, JP14.A0, R4.2, R7.1
WDIR2: D15.A, D16.C, JP21.12, JP21.A0, R21.2, R24.1
WDIR3: D21.A, D22.C, JP28.12, JP28.A0, R31.2, R34.1
WDIR4: D27.A, D28.C, JP35.12, JP35.A0, R41.2, R44.1
WDIR5: D33.A, D34.C, JP42.12, JP42.A0, R51.2, R54.1
WSPEED: D9.A, D10.C, JP9.16, JP9.D3, R14.1
WSPEED1: D1.A, D2.C, JP14.16, JP14.D3, R5.1
WSPEED2: D13.A, D14.C, JP21.16, JP21.D3, R22.1
WSPEED3: D19.A, D20.C, JP28.16, JP28.D3, R32.1
WSPEED4: D25.A, D26.C, JP35.16, JP35.D3, R42.1
WSPEED5: D31.A, D32.C, JP42.16, JP42.D3, R52.1

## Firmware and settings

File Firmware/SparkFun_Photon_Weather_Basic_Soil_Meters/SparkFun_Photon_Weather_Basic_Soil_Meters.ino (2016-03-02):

/******************************************************************************
  SparkFun_Photon_Weather_Basic_Soil_Meters.ino
  SparkFun Photon Weather Shield basic example with soil moisture and temp
  and weather meter readings including wind speed, wind direction and rain.
  Joel Bartlett @ SparkFun Electronics
  Original Creation Date: May 18, 2015

  Based on the Wimp Weather Station sketch by: Nathan Seidle
  https://github.com/sparkfun/Wimp_Weather_Station

  This sketch prints the temperature, humidity, barometric pressure, altitude,
  soil moisture, and soil temperature to the Seril port. This sketch also
  incorporates the Weather Meters avaialbe from SparkFun (SEN-08942), which allow
  you to measure Wind Speed, Wind Direction, and Rainfall. Upload this sketch
  after attaching a soil moisture and or soil temperature sensor and Wetaher
  Meters to test your connections.

  Hardware Connections:
	This sketch was written specifically for the Photon Weather Shield,
	which connects the HTU21D and MPL3115A2 to the I2C bus by default.
  If you have an HTU21D and/or an MPL3115A2 breakout,	use the following
  hardware setup:
      HTU21D ------------- Photon
      (-) ------------------- GND
      (+) ------------------- 3.3V (VCC)
       CL ------------------- D1/SCL
       DA ------------------- D0/SDA

    MPL3115A2 ------------- Photon
      GND ------------------- GND
      VCC ------------------- 3.3V (VCC)
      SCL ------------------ D1/SCL
      SDA ------------------ D0/SDA

    Soil Moisture Sensor ----- Photon
        GND ------------------- GND
        VCC ------------------- D5
        SIG ------------------- A1

    DS18B20 Temp Sensor ------ Photon
        VCC (Red) ------------- 3.3V (VCC)
        GND (Black) ----------- GND
        SIG (White) ----------- D4


  Development environment specifics:
  	IDE: Particle Dev
  	Hardware Platform: Particle Photon
                       Particle Core

  This code is beerware; if you see me (or any other SparkFun
  employee) at the local, and you've found our code helpful,
  please buy us a round!
  Distributed as-is; no warranty is given.
*******************************************************************************/
#include "SparkFun_Photon_Weather_Shield_Library.h"
#include "OneWire.h"
#include "spark-dallas-temperature.h"
//OneWire and DallasTemperature libraries are needed for DS18B20 Temp sensor

#define ONE_WIRE_BUS D4
#define TEMPERATURE_PRECISION 11
OneWire oneWire(ONE_WIRE_BUS);
DallasTemperature sensors(&oneWire);

#define SOIL_MOIST A1
#define SOIL_MOIST_POWER D5

int WDIR = A0;
int RAIN = D2;
int WSPEED = D3;

//Run I2C Scanner to get address of DS18B20(s)
//(found in the Firmware folder in the Photon Weather Shield Repo)
/***********REPLACE THIS ADDRESS WITH YOUR ADDRESS*************/
DeviceAddress inSoilThermometer =
{0x28, 0x6F, 0xD1, 0x5E, 0x06, 0x00, 0x00, 0x76};//Waterproof temp sensor address
/***********REPLACE THIS ADDRESS WITH YOUR ADDRESS*************/

//Global Variables
//-=-=-=-=-=-=-=-=-=-=-=-=-=-=-=-=-=-=-=-=-=-=-=-=-=-=-=-=
long lastSecond; //The millis counter to see when a second rolls by
byte seconds; //When it hits 60, increase the current minute
byte seconds_2m; //Keeps track of the "wind speed/dir avg" over last 2 minutes array of data
byte minutes; //Keeps track of where we are in various arrays of data
byte minutes_10m; //Keeps track of where we are in wind gust/dir over last 10 minutes array of data

//We need to keep track of the following variables:
//Wind speed/dir each update (no storage)
//Wind gust/dir over the day (no storage)
//Wind speed/dir, avg over 2 minutes (store 1 per second)
//Wind gust/dir over last 10 minutes (store 1 per minute)
//Rain over the past hour (store 1 per minute)
//Total rain over date (store one per day)

byte windspdavg[120]; //120 bytes to keep track of 2 minute average
int winddiravg[120]; //120 ints to keep track of 2 minute average
float windgust_10m[10]; //10 floats to keep track of 10 minute max
int windgustdirection_10m[10]; //10 ints to keep track of 10 minute max
volatile float rainHour[60]; //60 floating numbers to keep track of 60 minutes of rain

//These are all the weather values that wunderground expects:
int winddir = 0; // [0-360 instantaneous wind direction]
float windspeedmph = 0; // [mph instantaneous wind speed]
float windgustmph = 0; // [mph current wind gust, using software specific time period]
int windgustdir = 0; // [0-360 using software specific time period]
float windspdmph_avg2m = 0; // [mph 2 minute average wind speed mph]
int winddir_avg2m = 0; // [0-360 2 minute average wind direction]
float windgustmph_10m = 0; // [mph past 10 minutes wind gust mph ]
int windgustdir_10m = 0; // [0-360 past 10 minutes wind gust direction]
float rainin = 0; // [rain inches over the past hour)] -- the accumulated rainfall in the past 60 min
long lastWindCheck = 0;
volatile float dailyrainin = 0; // [rain inches so far today in local time]

float humidity = 0;
float tempf = 0;
double InTempC = 0;//original temperature in C from DS18B20
float soiltempf = 0;//converted temperature in F from DS18B20
float pascals = 0;
float altf = 0;
float baroTemp = 0;
int soilMoisture = 0;

int count = 0;

// volatiles are subject to modification by IRQs
volatile long lastWindIRQ = 0;
volatile byte windClicks = 0;
volatile unsigned long raintime, rainlast, raininterval, rain;

//Create Instance of HTU21D or SI7021 temp and humidity sensor and MPL3115A2 barrometric sensor
Weather sensor;

void update18B20Temp(DeviceAddress deviceAddress, double &tempC);//predeclare to compile

//Interrupt routines (these are called by the hardware interrupts, not by the main code)
//-=-=-=-=-=-=-=-=-=-=-=-=-=-=-=-=-=-=-=-=-=-=-=-=-=-=-=-=
void rainIRQ()
// Count rain gauge bucket tips as they occur
// Activated by the magnet and reed switch in the rain gauge, attached to input D2
{
  raintime = millis(); // grab current time
  raininterval = raintime - rainlast; // calculate interval between this and last event

    if (raininterval > 10) // ignore switch-bounce glitches less than 10mS after initial edge
  {
    dailyrainin += 0.011; //Each dump is 0.011" of water
    rainHour[minutes] += 0.011; //Increase this minute's amount of rain

    rainlast = raintime; // set up for next event
  }
}

void wspeedIRQ()
// Activated by the magnet in the anemometer (2 ticks per rotation), attached to input D3
{
  if (millis() - lastWindIRQ > 10) // Ignore switch-bounce glitches less than 10ms (142MPH max reading) after the reed switch closes
  {
    lastWindIRQ = millis(); //Grab the current time
    windClicks++; //There is 1.492MPH for each click per second.
  }
}

//---------------------------------------------------------------
void setup()
{
    // DS18B20 initialization
    sensors.begin();
    sensors.setResolution(inSoilThermometer, TEMPERATURE_PRECISION);

    pinMode(WSPEED, INPUT_PULLUP); // input from wind meters windspeed sensor
    pinMode(RAIN, INPUT_PULLUP); // input from wind meters rain gauge sensor

    pinMode(SOIL_MOIST_POWER, OUTPUT);//power control for soil moisture
    digitalWrite(SOIL_MOIST_POWER, LOW);//Leave off by defualt

    Serial.begin(9600);   // open serial over USB

    // Make sure your Serial Terminal app is closed before powering your device
    // Now open your Serial Terminal, and hit any key to continue!
    Serial.println("Press any key to begin");
    //This line pauses the Serial port until a key is pressed
    while(!Serial.available()) Spark.process();

    //Initialize the I2C sensors and ping them
    sensor.begin();

    /*You can only receive acurate barrometric readings or acurate altitiude
    readings at a given time, not both at the same time. The following two lines
    tell the sensor what mode to use. You could easily write a function that
    takes a reading in one made and then switches to the other mode to grab that
    reading, resulting in data that contains both acurate altitude and barrometric
    readings. For this example, we will only be using the barometer mode. Be sure
    to only uncomment one line at a time. */
    sensor.setModeBarometer();//Set to Barometer Mode
    //baro.setModeAltimeter();//Set to altimeter Mode

    //These are additional MPL3115A2 functions the MUST be called for the sensor to work.
    sensor.setOversampleRate(7); // Set Oversample rate
    //Call with a rate from 0 to 7. See page 33 for table of ratios.
    //Sets the over sample rate. Datasheet calls for 128 but you can set it
    //from 1 to 128 samples. The higher the oversample rate the greater
    //the time between data samples.

    sensor.enableEventFlags(); //Necessary register calls to enble temp, baro ansd alt

    seconds = 0;
    lastSecond = millis();

    // attach external interrupt pins to IRQ functions
    attachInterrupt(RAIN, rainIRQ, FALLING);
    attachInterrupt(WSPEED, wspeedIRQ, FALLING);

    // turn on interrupts
    interrupts();
}
//---------------------------------------------------------------
void loop()
{
  //Keep track of which minute it is
  if(millis() - lastSecond >= 1000)
  {

    lastSecond += 1000;

    //Take a speed and direction reading every second for 2 minute average
    if(++seconds_2m > 119) seconds_2m = 0;

    //Calc the wind speed and direction every second for 120 second to get 2 minute average
    float currentSpeed = get_wind_speed();
    //float currentSpeed = random(5); //For testing
    int currentDirection = get_wind_direction();
    windspdavg[seconds_2m] = (int)currentSpeed;
    winddiravg[seconds_2m] = currentDirection;
    //if(seconds_2m % 10 == 0) displayArrays(); //For testing

    //Check to see if this is a gust for the minute
    if(currentSpeed > windgust_10m[minutes_10m])
    {
      windgust_10m[minutes_10m] = currentSpeed;
      windgustdirection_10m[minutes_10m] = currentDirection;
    }

    //Check to see if this is a gust for the day
    if(currentSpeed > windgustmph)
    {
      windgustmph = currentSpeed;
      windgustdir = currentDirection;
    }

    if(++seconds > 59)
    {
      seconds = 0;

      if(++minutes > 59) minutes = 0;
      if(++minutes_10m > 9) minutes_10m = 0;

      rainHour[minutes] = 0; //Zero out this minute's rainfall amount
      windgust_10m[minutes_10m] = 0; //Zero out this minute's gust
    }

    //Get readings from all sensors
    getWeather();
    //Rather than use a delay, keeping track of a counter allows the photon to
    // still take readings and do work in between printing out data.
    count++;
    //alter this number to change the amount of time between each reading
    if(count == 5)
    {
       printInfo();
       count = 0;
    }
  }
}
//---------------------------------------------------------------
void printInfo()
{
  //This function prints the weather data out to the default Serial Port
      Serial.print("Wind_Dir:");
      switch (winddir)
      {
        case 0:
          Serial.print("North");
          break;
        case 1:
          Serial.print("NE");
          break;
        case 2:
          Serial.print("East");
          break;
        case 3:
          Serial.print("SE");
          break;
        case 4:
          Serial.print("South");
          break;
        case 5:
          Serial.print("SW");
          break;
        case 6:
          Serial.print("West");
          break;
        case 7:
          Serial.print("NW");
          break;
        default:
          Serial.print("No Wind");
          // if nothing else matches, do the
          // default (which is optional)
      }

      Serial.print(" Wind_Speed:");
      Serial.print(windspeedmph, 1);
      Serial.print("mph, ");

      Serial.print("Rain:");
      Serial.print(rainin, 2);
      Serial.print("in., ");

      Serial.print("Temp:");
      Serial.print(tempf);
      Serial.print("F, ");

      Serial.print("Humidity:");
      Serial.print(humidity);
      Serial.print("%, ");

      Serial.print("Baro_Temp:");
      Serial.print(baroTemp);
      Serial.print("F, ");

      Serial.print("Pressure:");
      Serial.print(pascals/100);
      Serial.print("hPa, ");
      //The MPL3115A2 outputs the pressure in Pascals. However, most weather stations
      //report pressure in hectopascals or millibars. Divide by 100 to get a reading
      //more closely resembling what online weather reports may say in hPa or mb.
      //Another common unit for pressure is Inches of Mercury (in.Hg). To convert
      //from mb to in.Hg, use the following formula. P(inHg) = 0.0295300 * P(mb)
      //More info on conversion can be found here:
      //www.srh.noaa.gov/images/epz/wxcalc/pressureConversion.pdf

      //If in altitude mode, print with these lines
      //Serial.print("Altitude:");
      //Serial.print(altf);
      //Serial.println("ft.");

      Serial.print("Soil_Temp:");
      Serial.print(soiltempf);
      Serial.print("F, ");

      Serial.print("Soil_Mositure:");
      Serial.println(soilMoisture);//Mositure Content is expressed as an analog
      //value, which can range from 0 (completely dry) to the value of the
      //materials' porosity at saturation. The sensor tends to max out between
      //3000 and 3500.
}
//---------------------------------------------------------------
void getSoilTemp()
{
    //get temp from DS18B20
    sensors.requestTemperatures();
    update18B20Temp(inSoilThermometer, InTempC);
    //Every so often there is an error that throws a -127.00, this compensates
    if(InTempC < -100)
      soiltempf = soiltempf;//push last value so data isn't out of scope
    else
      soiltempf = (InTempC * 9)/5 + 32;//else grab the newest, good data
}
//---------------------------------------------------------------
void getSoilMositure()
{
    /*We found through testing that leaving the soil moisture sensor powered
    all the time lead to corrosion of the probes. Thus, this port breaks out
    Digital Pin D5 as the power pin for the sensor, allowing the Photon to
    power the sensor, take a reading, and then disable power on the sensor,
    giving the sensor a longer lifespan.*/
    digitalWrite(SOIL_MOIST_POWER, HIGH);
    delay(200);
    soilMoisture = analogRead(SOIL_MOIST);
    delay(100);
    digitalWrite(SOIL_MOIST_POWER, LOW);

}
//---------------------------------------------------------------
void update18B20Temp(DeviceAddress deviceAddress, double &tempC)
{
  tempC = sensors.getTempC(deviceAddress);
}
//---------------------------------------------------------------
//Read the wind direction sensor, return heading in degrees
int get_wind_direction()
{
  unsigned int adc;

  adc = analogRead(WDIR); // get the current reading from the sensor

  // The following table is ADC readings for the wind direction sensor output, sorted from low to high.
  // Each threshold is the midpoint between adjacent headings. The output is degrees for that ADC reading.
  // Note that these are not in compass degree order! See Weather Meters datasheet for more information.

  //Wind Vains may vary in the values they return. To get exact wind direction,
  //it is recomended that you AnalogRead the Wind Vain to make sure the values
  //your wind vain output fall within the values listed below.
  if(adc > 2270 && adc < 2290) return (0);//North
  if(adc > 3220 && adc < 3299) return (1);//NE
  if(adc > 3890 && adc < 3999) return (2);//East
  if(adc > 3780 && adc < 3850) return (3);//SE

  if(adc > 3570 && adc < 3650) return (4);//South
  if(adc > 2790 && adc < 2850) return (5);//SW
  if(adc > 1580 && adc < 1610) return (6);//West
  if(adc > 1930 && adc < 1950) return (7);//NW

  return (-1); // error, disconnected?
}
//---------------------------------------------------------------
//Returns the instataneous wind speed
float get_wind_speed()
{
  float deltaTime = millis() - lastWindCheck; //750ms

  deltaTime /= 1000.0; //Covert to seconds

  float windSpeed = (float)windClicks / deltaTime; //3 / 0.750s = 4

  windClicks = 0; //Reset and start watching for new wind
  lastWindCheck = millis();

  windSpeed *= 1.492; //4 * 1.492 = 5.968MPH

  /* Serial.println();
   Serial.print("Windspeed:");
   Serial.println(windSpeed);*/

  return(windSpeed);
}
//---------------------------------------------------------------
void getWeather()
{
    // Measure Relative Humidity from the HTU21D or Si7021
    humidity = sensor.getRH();

    // Measure Temperature from the HTU21D or Si7021
    tempf = sensor.getTempF();
    // Temperature is measured every time RH is requested.
    // It is faster, therefore, to read it from previous RH
    // measurement with getTemp() instead with readTemp()

    //Measure the Barometer temperature in F from the MPL3115A2
    baroTemp = sensor.readBaroTempF();

    //Measure Pressure from the MPL3115A2
    pascals = sensor.readPressure();

    //If in altitude mode, you can get a reading in feet  with this line:
    //float altf = sensor.readAltitudeFt();

    getSoilTemp();//Read the DS18B20 waterproof temp sensor
    getSoilMositure();//Read the soil moisture sensor

    //Calc winddir
    winddir = get_wind_direction();

    //Calc windspeed
    windspeedmph = get_wind_speed();

    //Calc windgustmph
    //Calc windgustdir
    //Report the largest windgust today
    windgustmph = 0;
    windgustdir = 0;

    //Calc windspdmph_avg2m
    float temp = 0;
    for(int i = 0 ; i < 120 ; i++)
      temp += windspdavg[i];
    temp /= 120.0;
    windspdmph_avg2m = temp;

    //Calc winddir_avg2m
    temp = 0; //Can't use winddir_avg2m because it's an int
    for(int i = 0 ; i < 120 ; i++)
      temp += winddiravg[i];
    temp /= 120;
    winddir_avg2m = temp;

    //Calc windgustmph_10m
    //Calc windgustdir_10m
    //Find the largest windgust in the last 10 minutes
    windgustmph_10m = 0;
    windgustdir_10m = 0;
    //Step through the 10 minutes
    for(int i = 0; i < 10 ; i++)
    {
      if(windgust_10m[i] > windgustmph_10m)
      {
        windgustmph_10m = windgust_10m[i];
        windgustdir_10m = windgustdirection_10m[i];
      }
    }

    //Total rainfall for the day is calculated within the interrupt
    //Calculate amount of rainfall for the last 60 minutes
    rainin = 0;
    for(int i = 0 ; i < 60 ; i++)
      rainin += rainHour[i];
}

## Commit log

2015-02-23 Adding Hardware Files
    Adding Hardware Files
    [Spark_Photon_Weather_Shield.brd, Spark_Photon_Weather_Shield.sch]
2015-03-13 Adding I2C header
    Adding I2C header to connect any I2C peripherals desired to enhance the
    weather station.
    [Spark_Photon_Weather_Shield.brd, Spark_Photon_Weather_Shield.sch]
2015-03-20 Major Routing - Close to Proto
    Major Routing - Close to Proto. added lots of silk and jumper features.
    Finished routing.
    [Spark_Photon_Weather_Shield.brd, Spark_Photon_Weather_Shield.sch]
2015-03-20 Final touches before peer review
    Ran my own QC checklist and fixed a few minor details such as
    fiducials, labeling, more rerouting, etc.
    [Spark_Photon_Weather_Shield.brd, Spark_Photon_Weather_Shield.sch]
2015-03-20 Renaming
    Renaming files and folders to remove Spark name.
    [SparkFun_Photon_Weather_Shield.brd, SparkFun_Photon_Weather_Shield.sch]
2015-03-20 Peer Review complete
    Peer review with Jim, added 3.3V disable jumper for two power sources
    at once (debugging), minor edits.
    [SparkFun_Photon_Weather_Shield.brd, SparkFun_Photon_Weather_Shield.sch]
2015-03-20 Peer Review complete
    Peer Review complete
    [SparkFun_Photon_Weather_Shield.brd]
2015-03-23 Ready for QC Checklist
    Replaced all old Eagle parts with most up to date library parts, added
    a Dimension Route as well as the Milling Route, Fixed Trestrict and
    Restrict, which were on Keepout instead.
    [SparkFun_Photon_Weather_Shield.brd, SparkFun_Photon_Weather_Shield.sch]
2015-03-23 Ready for QC Checklist
    Brestrict, which were on Keepout instead.
    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
    [SparkFun_Photon_Weather_Shield.brd]
2015-03-24 QC Checklist Issues Addressed
    QC Checklist Issues Addressed: added PROD_IDs to few missing parts,
    changed Y junctions to T junctions, fixed pin 1 markings, added Values
    where needed.
    [SparkFun_Photon_Weather_Shield.brd, SparkFun_Photon_Weather_Shield.sch]
2015-03-24 Added DNP to a few connectors
    Added DNP to a few connectors that I missed and do not need to be
    populated.
    [SparkFun_Photon_Weather_Shield.brd, SparkFun_Photon_Weather_Shield.sch]
2015-03-25 Ready for Protos
    Moved Soil_Moisture from A2 to A1 and deleted unused Light net on A1.
    [SparkFun_Photon_Weather_Shield.brd, SparkFun_Photon_Weather_Shield.sch]
2015-04-03 Changed Name
    Changed silk to new name: Weather Shield for Photon
    [SparkFun_Photon_Weather_Shield.brd]
2015-04-03 Changed name
    Fixed silk on back too!!!
    [SparkFun_Photon_Weather_Shield.brd]
2015-05-22 Ready for Reds
    Added USART port, changed soil moisture vcc to D5, minor silk and route
    changes.
    [SparkFun_Photon_Weather_Shield.brd, SparkFun_Photon_Weather_Shield.sch]
2015-05-26 Ready for last QC Check
    Most recent changes pushed to github include
    -Locking Footprint added to Photon Template for selective soldering
    -updating Photon template to wider version for selective solder
    -breakout USART port
    -changing power on Soil Moisture from Vcc to D5
    -Minor route and silk changes.
    [SparkFun_Photon_Weather_Shield.brd, SparkFun_Photon_Weather_Shield.sch]
2015-05-28 Ready for Reds
    Ready for Reds
    [SparkFun_Photon_Weather_Shield.brd, SparkFun_Photon_Weather_Shield.sch]
2015-05-28 created panel v10
    [SparkFun_Photon_Weather_Shield_Panel_v10.brd]
2015-05-28 re-do, added more "route out" for GP
    [SparkFun_Photon_Weather_Shield_Panel_v10.brd]
2015-07-02 Updating Example Sketches
    Updating Example Sketches
    [SparkFun_Photon_Weather_Shield.sch]
2015-07-28 Added a delay before sleep
    The photon was going to sleep before the message was sent to
    wunderground, adding the delay before sleep ensures that the data makes
    it’s way over.
2015-07-28 Eliminated two sensor read requests
    Converted temps instead of making additional sensor reads. Save a tiny
    bit of time, save a tiny bit of power.
2015-08-20 Updated all examples to use new Weather Shield Lib
    Also added more comments and revised the altitude/barometer sections.
    [Case stand alone.skp, PhotonWeatherShieldCaseClip.skp, PhotonWeatherShieldCaseClip~.skp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]
2015-08-27 Moved Route out note to dimension layer
    Moved Route out note to dimension layer to match production files.
    [SparkFun_Photon_Weather_Shield.brd]
2016-03-02 Adding Simple Phant example
    Adding simpler Phant example for those who do not have extra sensors
    attached. Minor text cleanup.
2016-09-17 Initial fork for additional sensors
    This fork of Sparkfun’s Photon Weather shield is intended to build upon
    the basic code with support for some customized sensors.
2017-03-22 Fixed GET syntax
    Fixed GET syntax (added HTTP and r\n\r\n)
    Also - added listener to print the server response to serial for
    debugging
    [SparkFun_Photon_Weather_Wunderground.ino]
2018-06-05 Update w/ Correct Voltage Regulator Name
    The schematic was updated incorrectly with the voltage regulator name and specifications. Instead of the MIC5219, it is populated with the **MIC5205**.
    While the recommended operating voltage from the [datasheet](http://ww1.microchip.com/downloads/en/DeviceDoc/20005785A.pdf) is up to +16V, the actual stable voltage in real world conditions is actually about ~11.5V. This has been been tested and verified by @sfemark .
    [SparkFun_Photon_Weather_Shield.brd, SparkFun_Photon_Weather_Shield.sch]

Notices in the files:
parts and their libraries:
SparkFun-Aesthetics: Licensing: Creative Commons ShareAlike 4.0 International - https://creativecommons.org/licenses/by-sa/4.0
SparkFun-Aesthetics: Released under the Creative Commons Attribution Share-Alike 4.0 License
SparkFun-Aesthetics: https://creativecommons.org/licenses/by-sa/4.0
